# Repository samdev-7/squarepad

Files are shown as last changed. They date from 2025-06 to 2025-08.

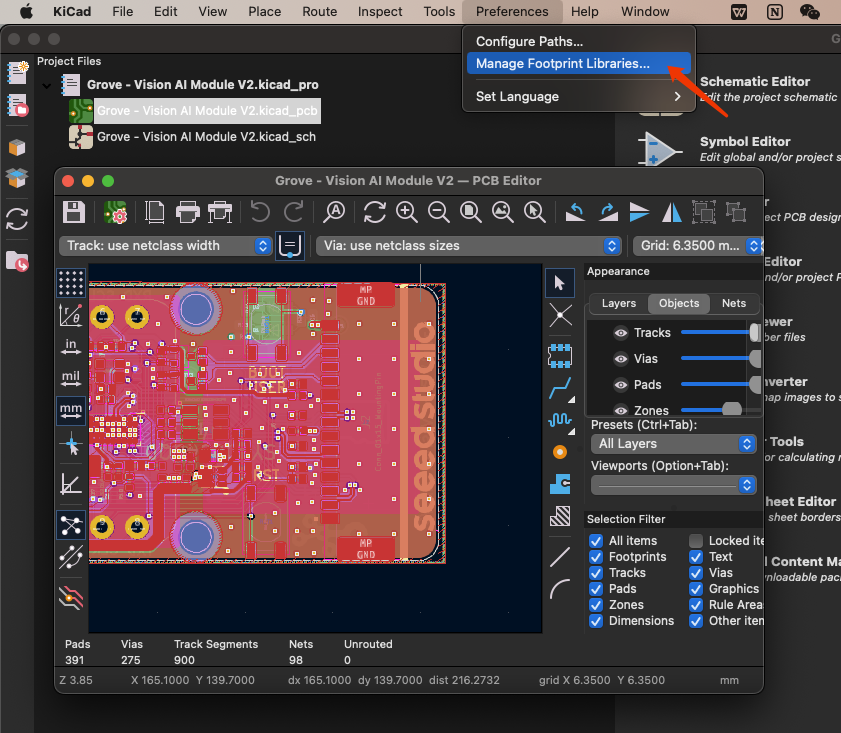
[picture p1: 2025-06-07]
pcb/OPL_Kicad_Library-master/images/4.png

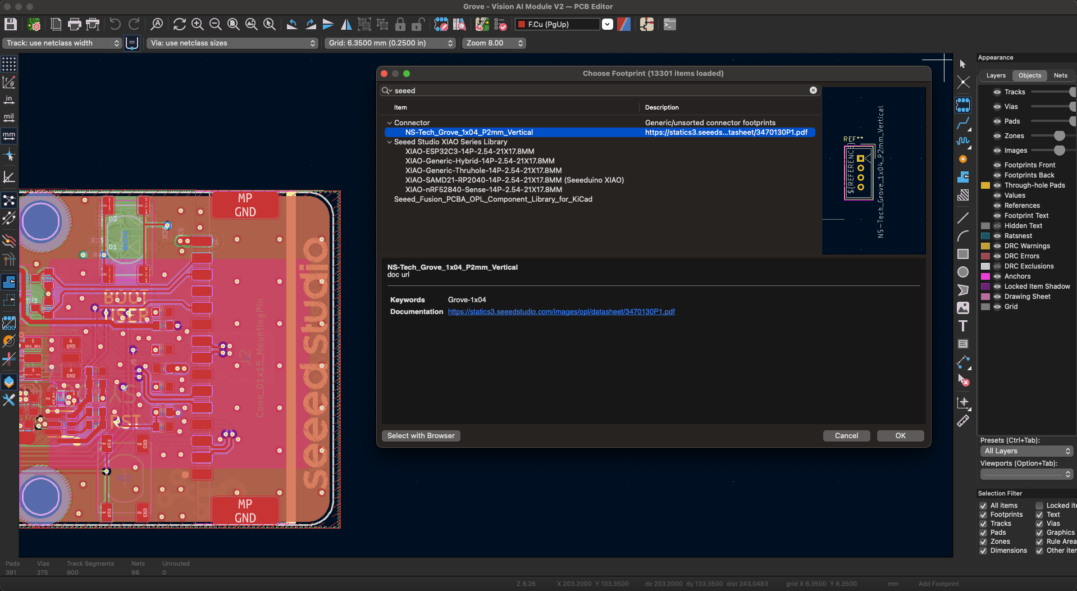
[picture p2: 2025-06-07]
pcb/OPL_Kicad_Library-master/images/19.png

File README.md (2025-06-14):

# Square Pad

A small but versatile macropad!

3D render of Square Pad
3D outline of Square Pad

Square pad is a KMK-powered, 8-key macropad with a rotary encoder, OLED display, and underglow lighting.  
It's inspired by the [Ocreeb MK2](https://github.com/sb-ocr/ocreeb-mk-2/tree/main) and was built for the [Hackpad](https://hackpad.hackclub.com/) program.

### Profile switching

The Square Pad can store and switch between several profiles, adapting the 8 keys and rotary encoder to whatever you need.  
To switch between presets, click the rotary encoder, rotate it to select a profile (shown on the OLED screen), and click to confirm. The underglow lighting will change colors, letting you know the current profile at a glance.

# Design

This is my first time designing a macropad/keyboard! Tons of Googling and bugging others here and there, but I (hopefully) did it!

## PCB

A total of 0 vias are on the PCB, ignoring THT and mounting holes. (there's no benefit to this, don't ask why)

Schematic of the Square Pad PCB

Layout of the Square Pad PCB

The PCB was designed in KiCad

## Case

The entire case can be 3D printed in 3 parts and assembled only with 6 M2x16mm screws and a tiny bit of hot glue for the screen. Each part is optimized for printability and quality with almost no supports.

3D exploded view of Square Pad

The case was designed in Onshape

## Firmware

Square Pad is powered by custom firmware written with [KMK](https://github.com/KMKfw/kmk_firmware). The custom firmware enabled easy profile switching and configuration.

# BOM

Everything you need to make your own Square Pad, minus the solder, glue, sweat, and tears.

## Electronics

- 1x XIAO RP2040 (with headers)
- 1x EC11E Rotary Encoder (with switch)
- 1x Rotary Encoder Knob
- 1x 0.91" OLED Display
- 8x Cherry MX Switches
- 8x Blank DSA Keycaps
- 9x Diode (THT)
- 12x SK6812 Mini LEDs
- Wires (for display)

## Case

- 6x M2x16mm Screw
- 1x case_top.stl
- 1x case_mid.stl
- 1x case_btm.stl
- 4x 10mm Rubber Feet (or just use hot glue)

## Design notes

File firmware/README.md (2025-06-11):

# Firmware

This folder contains the Firmware for Squre Pad, powered by KMK.

To install, download CircuitPython 9.x, install KMK, and the libraries: `neopixel`, `adafruit_display_text`, and `adafruit_displayio_ssd1306`, and copy all the Python files in this directory over.

Setup your profiles in `profile.py`.

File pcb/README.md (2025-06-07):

# PCB

This folder contains the PCB for the Squre Pad, designed in KiCad 8.0

To manufacture your own Square Pad PCB, the gerbers for JLCPCB are in `/production`.

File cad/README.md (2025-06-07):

# CAD

This folder contains the CAD for the Squre Pad.
The original CAD is available on Onshape: https://cad.onshape.com/documents/7a4a3820c147ef8980f0307c/w/4826e08d39faab4cb08c24dd/e/5c91f6f37143b2659c962470

## Case

To make the case, print one of each file in `/production/case`, models are already in the recommended orientation.  
The models have been optimized to require minimal supports. Supports are only needed for horizontals overhangings in the top part, and depending on your printer's bridging abilities, the USB Type-C port in the middle part may need supports.

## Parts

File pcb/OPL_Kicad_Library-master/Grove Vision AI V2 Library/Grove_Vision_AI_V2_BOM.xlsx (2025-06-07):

Layer Jump | Number | Name | Specification | Operating Temperature | MPN Code | Quantity | Base | Plug Position | Process
N | 301010000 | SMD RES 0R-5%-1/16W;0402 |  | -55°C to 155°C | RC0402JR-070RL | 3 | 1 | R29,R30,R39 | SMT1
N | 301010004 | SMD RES 10K-5%-1/16W;0402 |  | -55°C to 155°C | RC0402JR-0710KL | 7 | 1 | R5,R7,R8,R23,R24,R31,R38 | SMT1
N | 301010008 | SMD RES 510K-5%-1/16W;0402 |  | -55°C to 155°C | RC0402JR-07510KL | 1 | 1 | R35 | SMT1
N | 301010456 | SMD RES 100K-1%-1/16W;0402 |  | -55°C to 155°C | RC0402FR-07100KL | 7 | 1 | R6,R10,R11,R16,R32,R33,R37 | SMT1
N | 301010495 | SMD RES;5.1K-1%-1/16W;0402 |  | -55°C to 155°C | RC0402FR-075K1L | 3 | 1 | R2,R3,R36 | SMT1
N | 301010746 | SMD RES 2.2K-1%-1/16W;0402 |  | -55°C to 155°C | RC0402FR-072K2L | 10 | 1 | R1,R4,R13,R14,R15,R19,R20,R21,R22,R40 | SMT1
N | 301011331 | SMD RES 22.1K-1%-1/16W;0402 |  | -55°C to 155°C | RC0402FR-0722K1L | 2 | 1 | R26,R34 | SMT1
N | 302010004 | SMD CAP Ceramic 100nF-16V-10%-X7R;0402 |  | -55°C to 125°C | CC0402KRX7R7BB104 | 18 | 1 | C5,C8,C13,C20,C21,C22,C23,C24,C25,C26,C27,C29,C30,C31,C32,C35,C36,C39 | SMT1
N | 302010006 | SMD CAP Ceramic 10nF-50V-10%-X7R;0402 |  | -55°C to 125°C | CC0402KRX7R9BB103 | 1 | 1 | C3 | SMT1
N | 302010049 | SMD CAP Ceramic 12pF-50V-5%-NPO;0402 |  | -55°C to 125°C | CC0402JRNPO9BN120 | 2 | 1 | C14,C15 | SMT1
N | 302010051 | SMD CAP Ceramic 220nF-16V-10%-X7R;0402 |  | -55°C to 125°C | CC0402KRX7R7BB224 | 1 | 1 | C16 | SMT1
N | 302010407 | SMD CAP Ceramic 4.7uF-10V-10%-X5R;0402 |  | -55°C to 85°C | CC0402KRX5R6BB475 | 7 | 1 | C4,C6,C7,C9,C10,C28,C34 | SMT1
N | 302010519 | SMD CAP Ceramic 10uF-10V-20%-X5R;0402 |  | -55°C to 85°C | CC0402MRX5R6BB106 | 2 | 1 | C11,C37 | SMT1
N | 302013249 | SMD CAP Ceramic 1uF-10V-10%-X5R;0402 |  | -55°C to 85°C | CL05A105KP5NNNC | 5 | 1 | C1,C2,C17,C18,C19 | SMT1
N | 303010544 | SMD Inductor 4.7uH-20%-1.1A;0806 |  | -40°C to 105°C | VLS201610HBX-4R7M-1 | 1 | 1 | L1 | SMT1
N | 303011858 | SMD Inductor 470nH-20%-2.6A;0603 |  | -40°C to 125°C | TFM160808ALC-R47MTAA | 2 | 1 | L2,L3 | SMT1
N | 304011053 | SMD Diode Schottky 40V-1A;SOD-323 |  |  | B5819WS SL | 4 | 1 | D1,D2,D3,D4 | SMT1
N | 304090121 | SMD LED Clear-Green;0402 | As posted |  | BL-HGE37A-AV-TRB | 1 | 1 | LED2 | SMT1
N | 304090746 | SMD LED Clear-Yellow;0402 | As posted |  | 16-213/Y2C-AN2Q1B/3T | 1 | 1 | LED1 | SMT1
N | 305030071 | SMD MOSFET N-CH 20V-500mA;SOT-523 |  |  | CJ1012 | 5 | 1 | Q1,Q2,Q3,Q4,Q5 | SMT1
N | 306011444 | SMD Crystal;24MHz-12pF-10ppm-4P-2.0*1.6*0.5mm |  | -40°C to 85°C | Y2400FE001 | 1 | 1 | X1 | SMT1
N | 310011697 | SMD IC MCU;Dual Cortex-M55 Core(Max 400MHz)-With a 400MHz NPU;WLCSP-65 | L5.58*W2.27mm | -40°C to 85°C | HX6538-A01TWA | 1 | 1 | U1 | SMT1
N | 310032794 | SMD IC PMIC;DCDC Buck-ADJ-2.2MHz-4A;DFN1.5×1.5-6 |  | -40°C to 85°C | SY80004DQD | 2 | 1 | U4,U6 | SMT1
N | 310032813 | SMD IC PMIC;LDO-1.8V-300mA;XTDFN-1*1-4L |  | -40°C to 125°C | SGM2036S-1.8XXDH4G/TR | 1 | 1 | U3 | SMT1
N | 310071431 | SMD IC Interface USB to High Speed TTL;QFN16 | USB to High-Speed Serial Port | -40°C to 85°C | CH343P | 1 | 1 | U2 | SMT1
N | 310091468 | SMD IC Memory;128Mbit-1.8V;SOIC-8 |  | -40°C to 85°C | W25Q128JWSIQ | 1 | 1 | U5 | SMT1
N | 311020009 | SMD Top Button 4N;4P-L4.6*W3.2*H2.5mm |  | -20°C to 70°C | SKRPADE010 | 1 | 1 | RST1 | SMT1
N | 311020518 | SMD Top Button 1.57N;4P-L4.6*W3.2*H2.5mm |  | -30°C to 85°C | SKRPABE010 | 1 | 1 | BOOT1 | SMT1
N | 312030502 | SMD DIGITAL MIC OMNI -26dBFS;OCLGA-4:3.5*2.65*0.94mm |  | -40˚C to 100˚C | MSM261D3526H1CPM | 1 | 1 | MIC1 | SMT1
N | 319015667 | PCB;Grove - Vision AI Module V2 -蓝油白字-4层 | 20*40*1.6mm-ENIG-FR4;Steel mesh code；404012305 |  |  | 1 | 1 |  | SMT1
N | 320011358 | SMD USB TYPE C-W/P;12+4P-8.94*7.35*3.26mm |  | -30°C to 85°C | USB-31C-F-16P-L7.35 | 1 | 1 | J1 | SMT1
N | 320031231 | DIP Black Female Header VERT;1*7P-2.54-5.0mm |  | -40℃ to 105℃ |  | 2 | 1 | P8,P9 | Unit
N | 320060904 | SMD FPC CONN Bottom Contact;15P-1.0mm;L19.9*W6.76*H2.0mm |  | -30°C to 85°C | ST-FPC-W102015-D | 1 | 1 | J2 | SMT1
N | 320090535 | SMD uSD Card Holder;9+4P-L11.25*W6.96*H1.42mm |  | -25°C to 70°C | ST-TF-MR267 | 1 | 1 | J5 | SMT1
N | 320110032 | SMD Grove Female Header-Beige;4P-2.0-90D | 2.0-4PHorizontal Mount with Locking Socket |  | PHS-4A horizontal mount | 1 | 1 | J3 | SMT1

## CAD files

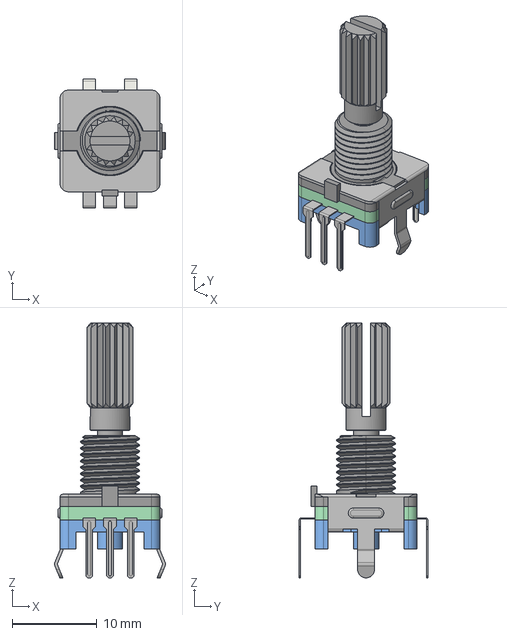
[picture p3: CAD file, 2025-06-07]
pcb/3d/EC11_Rotary_Encoder_Switched.step
13.1 x 15.3 x 30.1 mm

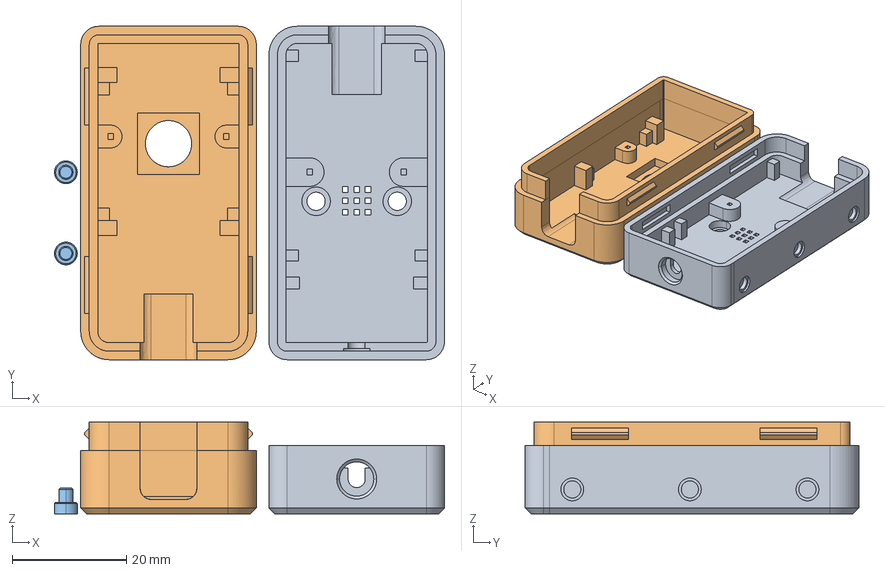
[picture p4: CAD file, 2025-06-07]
pcb/OPL_Kicad_Library-master/Grove Vision AI V2 Library/himax.stp
68.4 x 58.5 x 16.1 mm

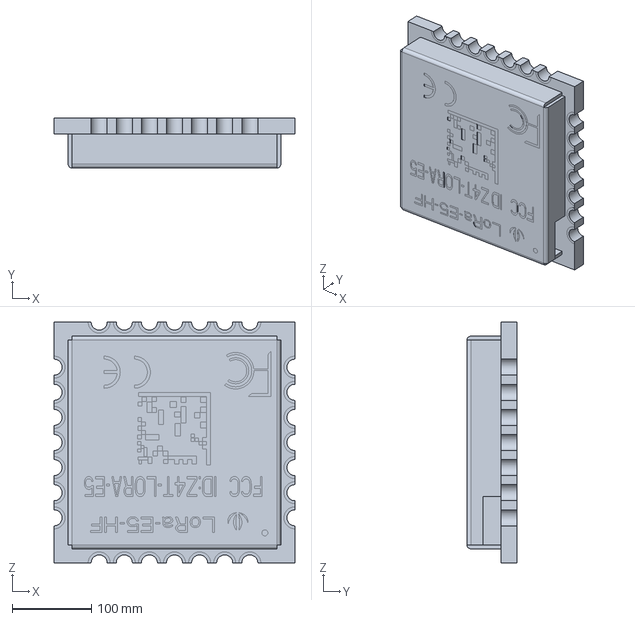
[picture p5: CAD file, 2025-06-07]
pcb/OPL_Kicad_Library-master/Seeed Studio Wio Series/Wio-E5-LE/LoRa-E5-LE-HF_3D_File.stp
304.8 x 63.8 x 304.8 mm

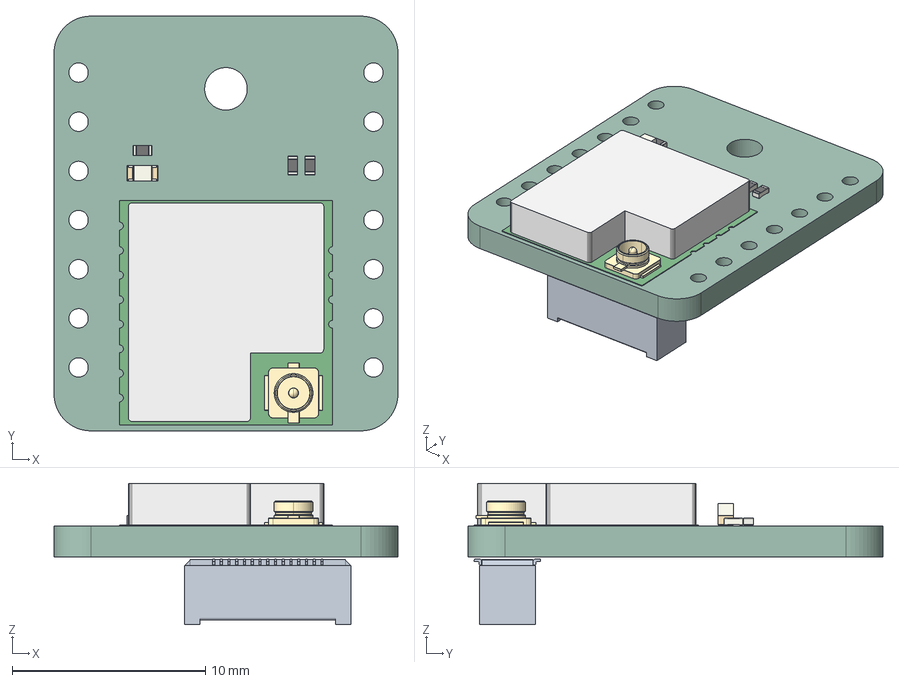
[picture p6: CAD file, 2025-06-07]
pcb/OPL_Kicad_Library-master/Seeed Studio Wio Series/Wio-SX1262/Wio-SX1262_for_XIAO_3D_file.step
17.8 x 21.4 x 7.30 mm
R_0402_1005Metric x 3
LED_0603_1608Metric
PCB
BF04-30pin-35H
Wio-SX1262 for XIAO V1.0_PCB

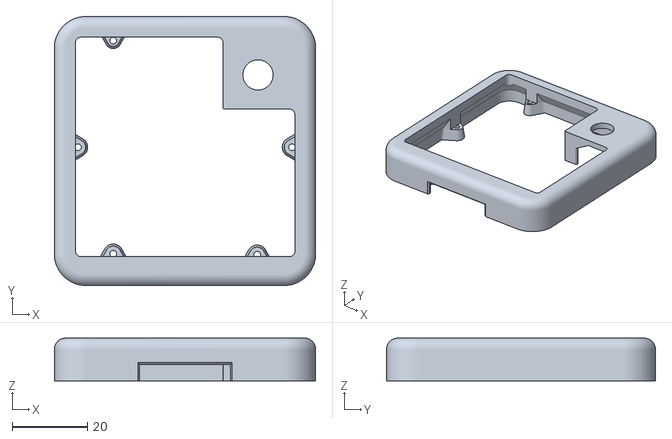
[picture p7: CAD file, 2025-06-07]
production/case/case_top.stl
69.3 x 71.3 x 11.4

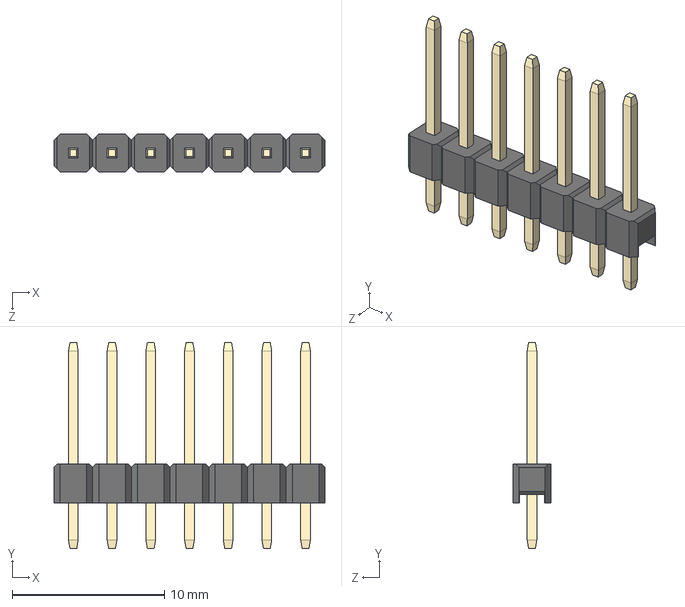
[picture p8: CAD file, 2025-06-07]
pcb/3d/1x7 Male Pin Header.step
17.8 x 13.5 x 2.50 mm

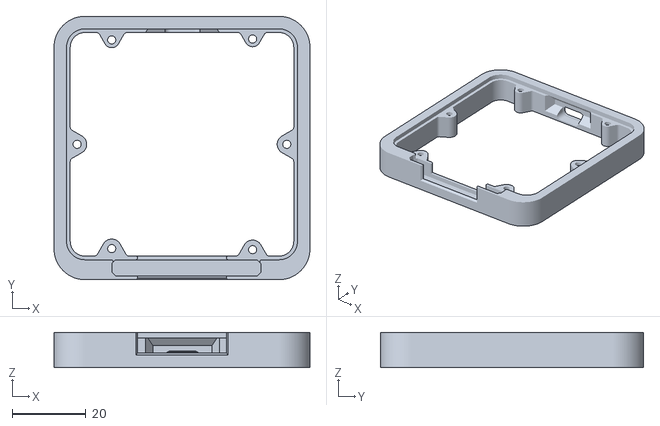
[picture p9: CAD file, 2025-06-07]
production/case/case_mid.stl
69.3 x 71.3 x 9.60

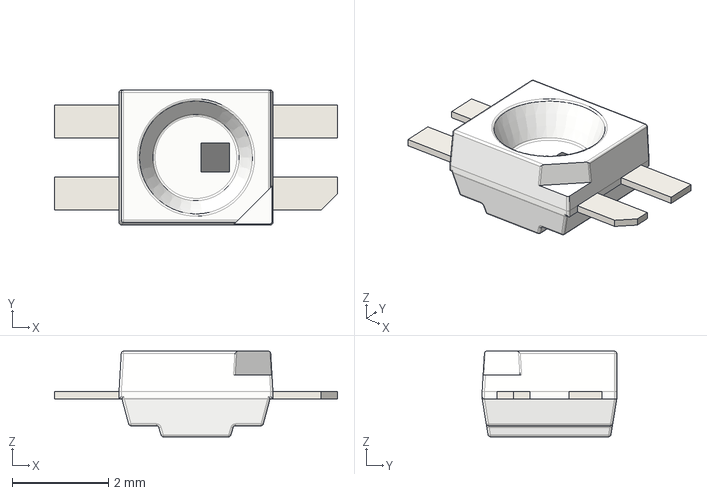
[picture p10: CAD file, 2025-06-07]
pcb/3d/LED_SK6812MINI-E.step
5.88 x 2.80 x 1.78 mm

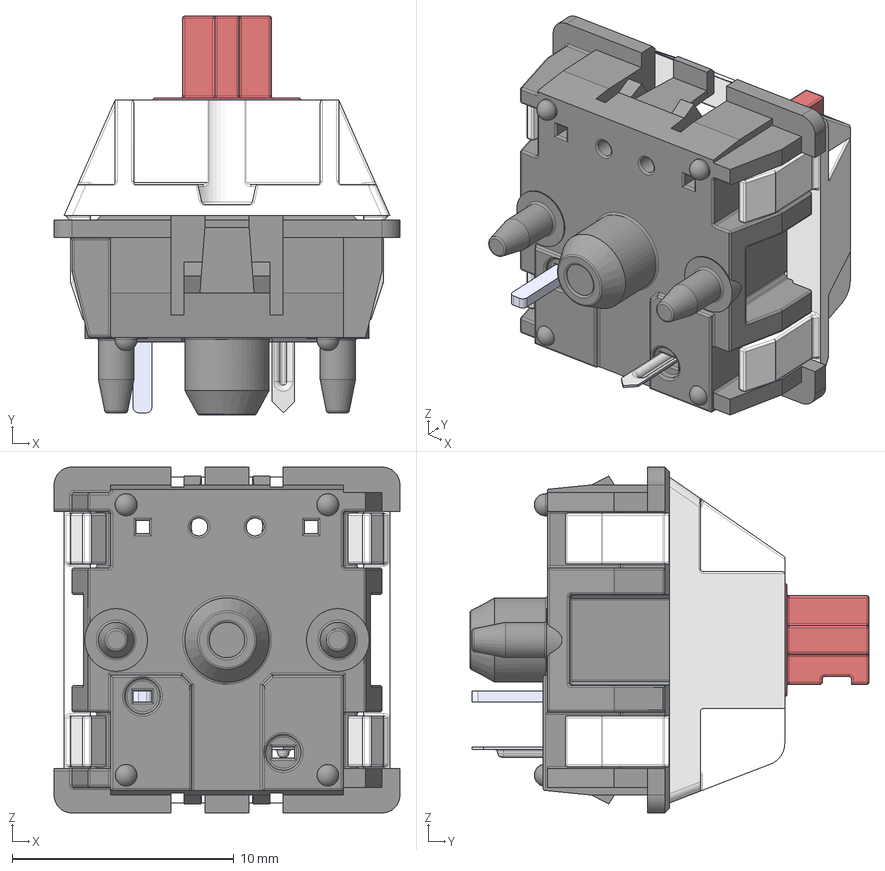
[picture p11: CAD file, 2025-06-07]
pcb/3d/Cherry MX-No LED.step
15.6 x 18.0 x 15.6 mm
Bottom
Pulsador
Top
Pieza5^Cherry MX
Pin1
Pin2

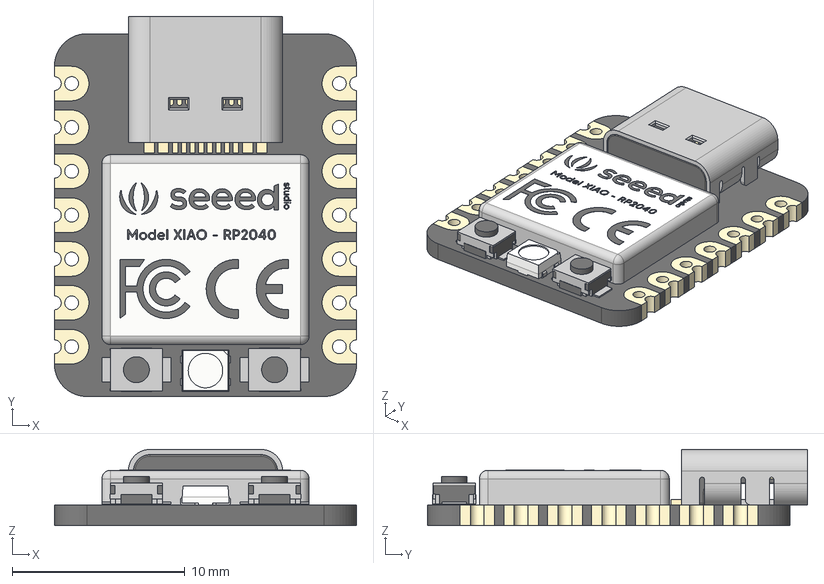
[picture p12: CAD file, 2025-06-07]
pcb/3d/Seeed Studio XIAO RP2040 v26.step
17.5 x 22.0 x 4.40 mm
type-c v2
smd_button v3
DOUT
DIN
VSS
VDD
smd_button v3(Mirror)

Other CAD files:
pcb/OPL_Kicad_Library-master/Grove Vision AI V2 Library/himax.3mf

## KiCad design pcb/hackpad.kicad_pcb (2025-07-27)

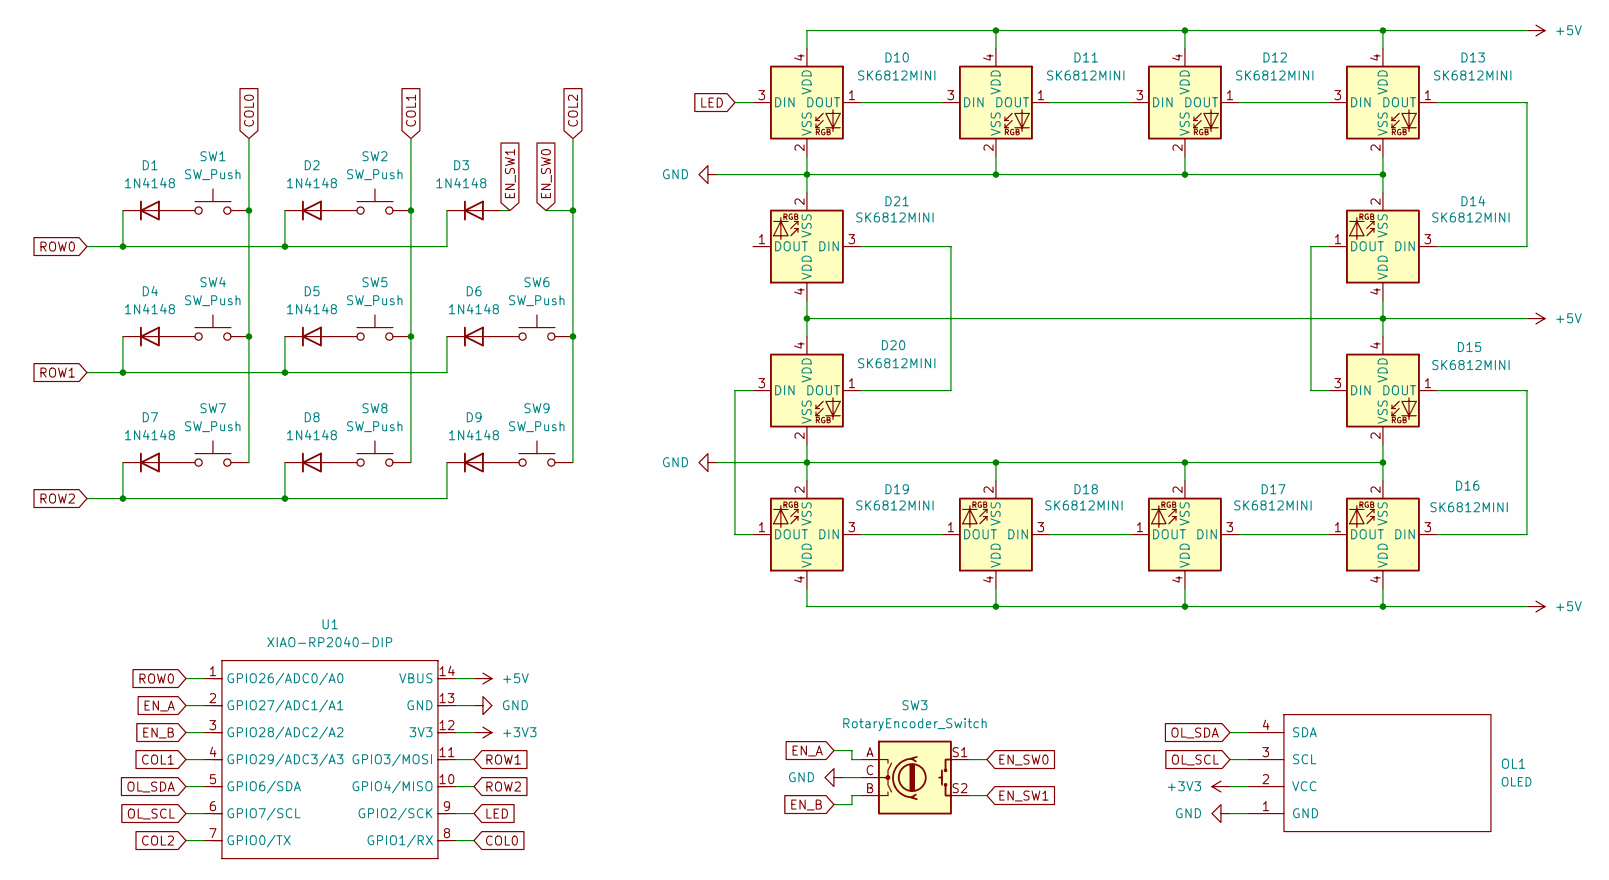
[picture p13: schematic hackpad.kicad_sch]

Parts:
D1, D2, D3, D4, D5, D6, D7, D8, D9: 1N4148; D_DO-35_SOD27_P7.62mm_Horizontal
D10, D11, D12, D13, D14, D15, D16, D17, D18, D19, D20, D21: SK6812MINI; LED_SK6812MINI_PLCC4_3.5x3.5mm_P1.75mm
OL1: OLED; SSD1306-0.91-OLED-4pin-128x32
SW1, SW2, SW4, SW5, SW6, SW7, SW8, SW9: SW_Push; SW_Cherry_MX_1.00u_PCB
SW3: RotaryEncoder_Switch; RotaryEncoder_Alps_EC11E-Switch_Vertical_H20mm
U1: XIAO-RP2040-DIP

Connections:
+3V3: OL1.2 (VCC), U1.12 (3V3)
+5V: D10.4 (VDD), D11.4 (VDD), D12.4 (VDD), D13.4 (VDD), D14.4 (VDD), D15.4 (VDD), D16.4 (VDD), D17.4 (VDD), D18.4 (VDD), D19.4 (VDD), D20.4 (VDD), D21.4 (VDD), U1.14 (VBUS)
COL0: SW1.2, SW4.2, SW7.2, U1.8 (GPIO1/RX)
COL1: SW2.2, SW5.2, SW8.2, U1.4 (GPIO29/ADC3/A3)
COL2: SW3.S1, SW6.2, SW9.2, U1.7 (GPIO0/TX)
EN_A: SW3.A, U1.2 (GPIO27/ADC1/A1)
EN_B: SW3.B, U1.3 (GPIO28/ADC2/A2)
EN_SW1: D3.2 (A), SW3.S2
GND: D10.2 (VSS), D11.2 (VSS), D12.2 (VSS), D13.2 (VSS), D14.2 (VSS), D15.2 (VSS), D16.2 (VSS), D17.2 (VSS), D18.2 (VSS), D19.2 (VSS), D20.2 (VSS), D21.2 (VSS), OL1.1 (GND), SW3.C, U1.13 (GND)
LED: D10.3 (DIN), U1.9 (GPIO2/SCK)
unnamed: D1.2 (A), SW1.1
unnamed: D2.2 (A), SW2.1
unnamed: D4.2 (A), SW4.1
unnamed: D5.2 (A), SW5.1
unnamed: D6.2 (A), SW6.1
unnamed: D7.2 (A), SW7.1
unnamed: D8.2 (A), SW8.1
unnamed: D9.2 (A), SW9.1
unnamed: D10.1 (DOUT), D11.3 (DIN)
unnamed: D11.1 (DOUT), D12.3 (DIN)
unnamed: D12.1 (DOUT), D13.3 (DIN)
unnamed: D13.1 (DOUT), D14.3 (DIN)
unnamed: D14.1 (DOUT), D15.3 (DIN)
unnamed: D15.1 (DOUT), D16.3 (DIN)
unnamed: D16.1 (DOUT), D17.3 (DIN)
unnamed: D17.1 (DOUT), D18.3 (DIN)
unnamed: D18.1 (DOUT), D19.3 (DIN)
unnamed: D19.1 (DOUT), D20.3 (DIN)
unnamed: D20.1 (DOUT), D21.3 (DIN)
OL_SCL: OL1.3 (SCL), U1.6 (GPIO7/SCL)
OL_SDA: OL1.4 (SDA), U1.5 (GPIO6/SDA)
ROW0: D1.1 (K), D2.1 (K), D3.1 (K), U1.1 (GPIO26/ADC0/A0)
ROW1: D4.1 (K), D5.1 (K), D6.1 (K), U1.11 (GPIO3/MOSI)
ROW2: D7.1 (K), D8.1 (K), D9.1 (K), U1.10 (GPIO4/MISO)

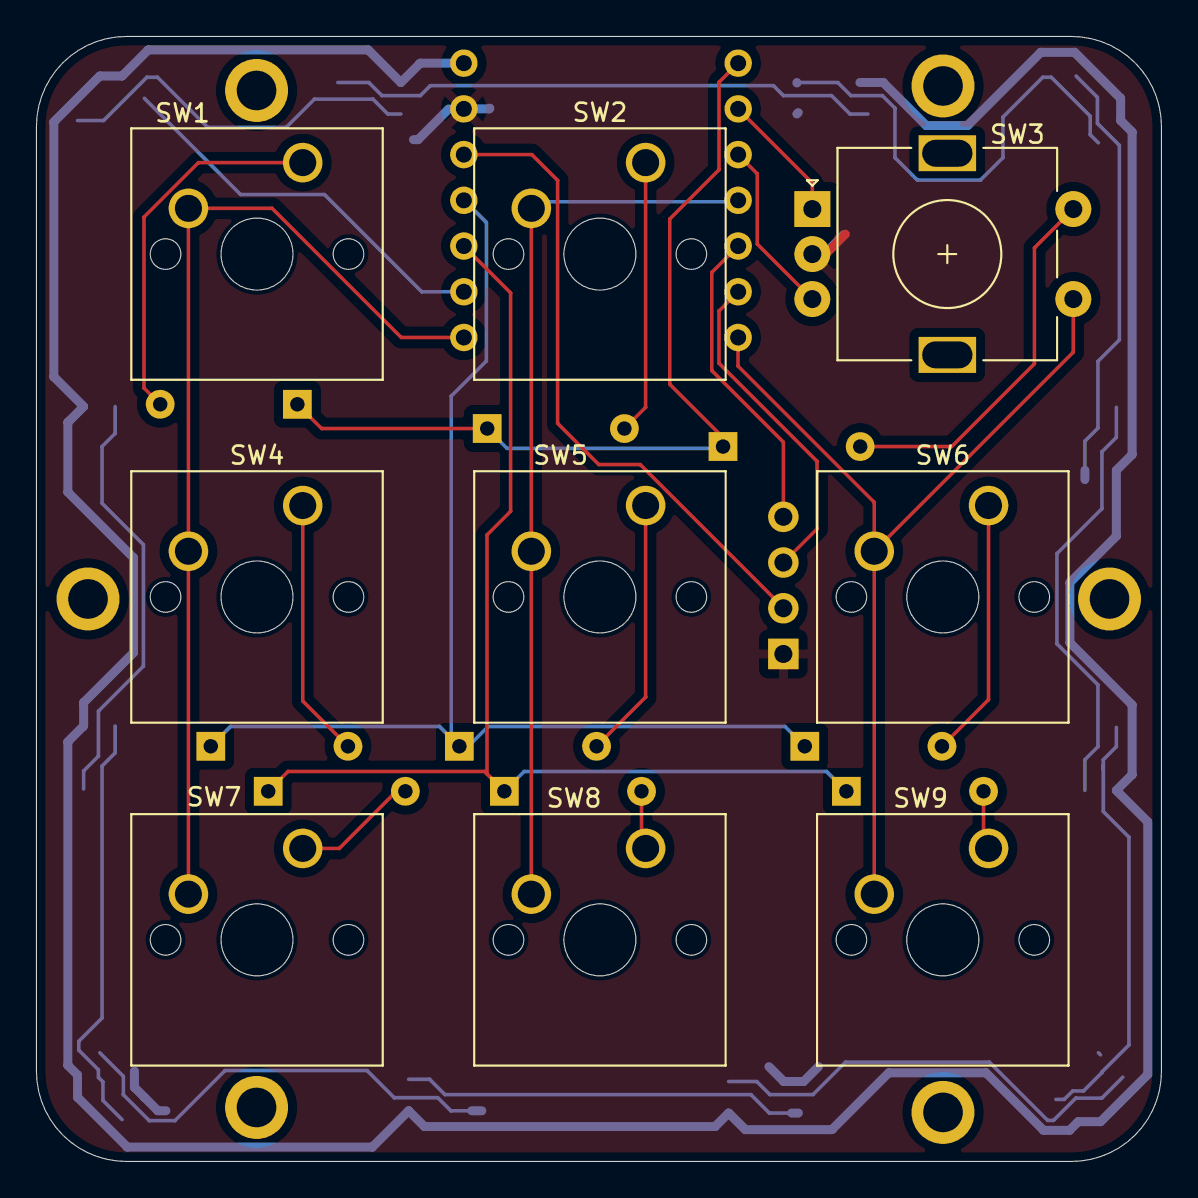
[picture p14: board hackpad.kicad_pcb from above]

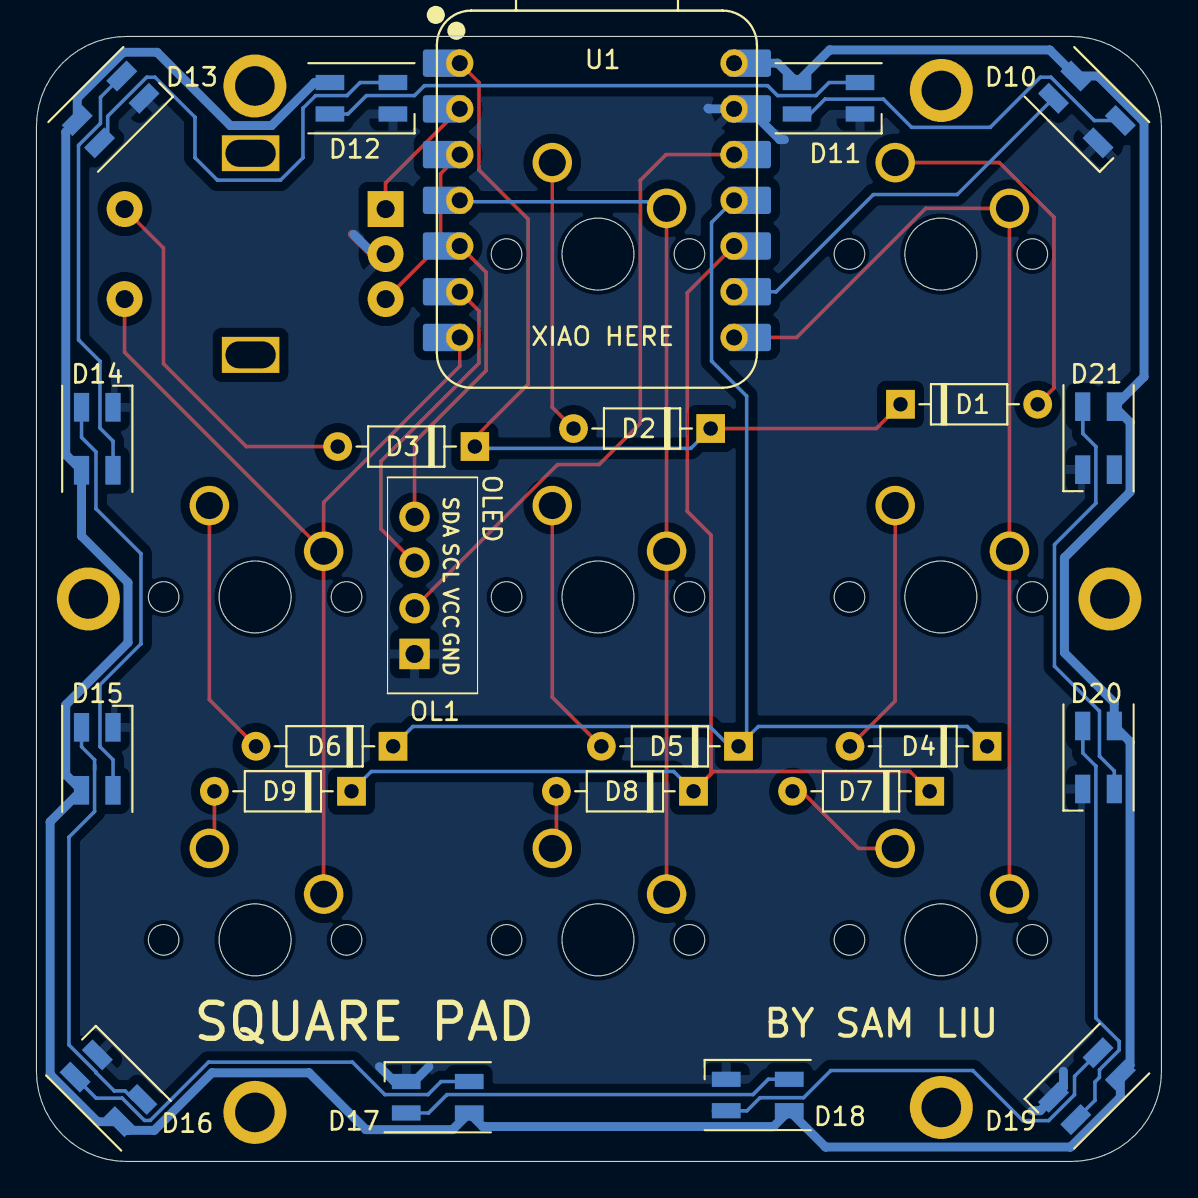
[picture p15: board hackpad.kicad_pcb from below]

Board: 2 copper layers, 62.5 x 62.5 mm, 32 parts (23 on the bottom side), 34 nets.

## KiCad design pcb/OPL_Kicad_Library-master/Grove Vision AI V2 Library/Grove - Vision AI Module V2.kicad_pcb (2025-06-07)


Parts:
BOOT1: SW_Push; SW_Push_1P1T_NO_Vertical_Wuerth_434133025816
C1, C2, C17, C18, C19: 1uF; C0402
C3: 10nF; C0402
C4, C6, C7, C9, C10, C28, C34: 4.7uF; C0402
C5, C8, C13, C20, C21, C22, C23, C24, C25, C26, C27, C29, C30, C31, C32, C35, C36, C39: 100nF; C0402
C11, C37: 10uF; C0402
C14, C15: 12pF; C0402
C16: 220nF; C0402
D1, D2, D3, D4: B5819WS; D0805_SOD323
D5, D6, D7, D8: DNP; R0402; MPN DF2S6.8FS
J1: USB_C_Receptacle_USB2.0; USB2.0-TYPE-C
J2: Conn_01x15_MountingPin; FPC_DNC_15P_1.0mm
J3: Conn_01x04_MountingPin; 4P-SMD-2.0mm-RIGHT
J5: ST-TF-MR267; SD-TF-MR267; MPN SD-TF-MR267
L1: VLS201610HBX-4R7M-1; L0806
L2, L3: 470nH; L0603
LED1: Yellow; LED0402
LED2: Green; LED0402
M1: XIAO Connector/DNP; XIAO_Socket
MIC1: MSM261D3526H1CPM; MIC6P-3.5X2.65X0.94MM
Q1, Q2, Q3, Q4, Q5: CJ1012; SOT523
R1, R4, R13, R14, R15, R19, R20, R21, R22, R40: 2.2k; R0402
R2, R3, R36: 5.1k; R0402
R5, R7, R23, R24: 10k; R0402
R6, R16, R32, R33: 100K; R0402; Power Rating 1%; MPN RC0402JR-074K7L
R8, R31, R38: 10K; R0402; Power Rating 5%; MPN RC0402JR-074K7L
R9, R12, R17, R18, R25, R27, R28: DNP; R0402
R10, R11, R37: 100k; R0402
R26, R34: 22K; R0402; Power Rating 1%; MPN RC0402JR-074K7L
R29, R30, R39: 0R; R0402
R35: 510k; R0402
RST1: SW_Push; SW_Push_1P1T_NO_Vertical_Wuerth_434133025816
TP1, TP2, TP3: Test Point; TP-D35MIL; Part Type Test Point
U1: HX6538; WLCSP65_5.6x2.3x0.56mm
U2: CH343P; QFN-16-EP_3x3mm_P0.5mm_EP1x1mm
U3: WR0331-18FF4R; X2SON-4
U4, U6: SY80004DQD; DFN6-0.5-1.5X1.5X0.65MM; MPN SY80004DQD
U5: W25Q128JWSIQ; SOIC-8_5.23x5.23mm_P1.27mm
X1: 24MHz; 4P2016

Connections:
1V8: C13.1, C19.2, C20.1, C21.1, C28.1, C29.2, Q1.1 (G), Q2.1 (G), R5.1, R21.2, R22.2, R25.1, TP2.1 (T), U1.F3 (VDDIO_SIF1), U1.G3 (VDDA_RX), U1.H5 (VDDA_TX), U1.L2 (VDDIO_SIF2), U3.1 (OUT), U5.8 (VCC)
/0V9: C4.1, C7.1, L1.2, U1.L4 (DCDC_OUT)
BOOTOPT0: D3.1 (K), R11.1, U1.F4 (BOOT_OPT)
GND: C1.2, C2.2, C3.2, C4.2, C5.2, C6.2, C7.2, C8.1, C9.2, C10.2, C11.1, C13.2, C14.2, C15.1, C17.2, C18.2, C19.1, C20.2, C21.2, C22.2, C23.2, C24.1, C25.1, C26.2, C27.1, C28.2, C29.1, C30.1, C31.2, C34.2, C35.1, C37.1, C39.1, D5.1, D6.1, D7.1, D8.1, J1.A1_B1_A12_B12 (GND), J1.S1 (SHIELD), J2.1, J2.4, J2.7, J2.10, J2.MP (MountPin), J3.4, J3.MP (MountPin), J5.S1 (SHD1), J5.S2 (SHD2), J5.S3 (SHD3), J5.S4 (SHD4), J5.T6 (VSS), LED2.1 (K), M1.13 (GND), MIC1.4 (GND), MIC1.5 (L/R), MIC1.6 (GND), Q3.2 (S), R2.2, R3.2, R10.2, R11.2, R23.2, R26.1, R34.1, R37.2, RST1.2, TP3.1 (T), U1.C5 (GND1), U1.G4 (GND2), U1.H3 (GND3), U1.L3 (GND4), U1.M2 (GND5), U1.M4 (GND6), U2.2 (GND), U2.17 (EPAD), U3.2 (GND), U3.T (GND), U4.4 (GND), U5.4 (GND), U6.4 (GND), X1.2 (1), X1.4 (3)
GROVE_5V_IN: C18.1, C34.1, C35.2, J3.3, R14.1, R15.1, R31.2, R32.2, U6.6 (IN)
I2CS0_SCL/5V: J3.1, Q4.3 (D), R14.2
I2CS0_SDA/5V: J3.2, Q5.3 (D), R15.2
M_3V3_SCL: J2.13, Q1.3 (D), R19.2
M_3V3_SDA: J2.14, Q2.3 (D), R20.2
unnamed: BOOT1.2, R4.2
unnamed: D1.2 (A), R36.2
unnamed: C9.1, C10.1, C27.2, D2.1 (K), D4.1 (K), R6.2, R8.2, U4.6 (IN)
unnamed: BOOT1.1, D3.2 (A), R36.1
unnamed: J1.A5 (CC1), R2.1
unnamed: J1.B5 (CC2), R3.1
unnamed: LED1.2 (A), R38.1
unnamed: LED1.1 (K), Q3.3 (D)
unnamed: LED2.2 (A), R24.2
unnamed: M1.12 (3V3), R39.2
unnamed: MIC1.2 (CLK), R29.1
unnamed: MIC1.3 (DATA), R30.1
unnamed: Q3.1 (G), R37.1, R40.2
unnamed: R10.1, U1.E4 (TEST_MODE)
unnamed: L1.1, U1.L5 (VX1)
unnamed: C14.1, R35.1, U1.G2 (XTAL_24M_I), X1.3 (4)
unnamed: C15.2, R35.2, U1.F1 (XTAL_24M_O), X1.1 (2)
unnamed: C16.2, U2.13 (RTS)
unnamed: R8.1, U4.1 (EN)
unnamed: C32.1, R16.1, R26.2, U4.3 (FB)
unnamed: L2.1, U4.5 (LX)
unnamed: R6.1, U4.2 (PG)
unnamed: R31.1, U6.1 (EN)
unnamed: C36.1, R33.1, R34.2, U6.3 (FB)
unnamed: L3.1, U6.5 (LX)
unnamed: R32.1, U6.2 (PG)
PA0/3V3: M1.1 (D0/A0), U1.D4 (PA0)
PA1/VMUTE/3V3: J2.11, U1.C4 (PA1)
PA2/I2CS0_SCL/3V3: M1.6 (D5/SCL), Q4.2 (S), R1.1, R17.2, U1.A4 (PA2)
PA3/I2CS0_SDA/3V3: M1.5 (D4/SDA), Q5.2 (S), R13.1, R18.2, U1.B4 (PA3)
PB0/RX0/3V3: U1.A5 (PB0), U2.4 (TXD)
PB1/TX0/3V3: U1.B5 (PB1), U2.5 (RXD)
PB2/SSPIM_DO/3V3: D7.2, J5.T3 (CMD), M1.11 (D10/MOSI), R12.2, U1.N5 (PB2)
PB3/SSPIM_DI/3V3: D5.2, J5.T7 (DAT0), M1.10 (D9/MISO), R9.2, U1.M3 (PB3)
PB4/SSPIM_SCLK/3V3: D6.2, J5.T5 (CLOCK), M1.9 (D8/SCK), R27.2, U1.N4 (PB4)
PB5/SSPIM_~CS/3V3: D8.2, J5.T2 (CD/DAT3), R28.2, U1.N3 (PB5)
PB6/UART1_RX/3V3: M1.7 (D6/TX), U1.N1 (PB6)
PB7/UART1_TX/3V3: M1.8 (D7/RX/SS), U1.M1 (PB7)
PB8/3V3: M1.3 (D2/A2), U1.L1 (PB8)
PB9/PDM_CLK/3V3: R29.2, U1.F5 (PB9)
PB10/PDM_DATA0/3V3: R30.2, U1.G5 (PB10)
PB11/3V3: M1.2 (D1/A1), U1.J3 (PB11)
QSPI_CLK: U1.C2 (QSPI_CLK), U5.6 (CLK)
QSPI_CS: R5.2, U1.B2 (QSPI_CS), U5.1 (~CS)
QSPI_D0: U1.B1 (QSPI_DIO0), U5.5 (DI(IO0))
QSPI_D1: U1.D3 (QSPI_DIO1), U5.2 (DO(IO1))
QSPI_D2: U1.A1 (QSPI_DIO2), U5.3 (IO2)
QSPI_D3: U1.E3 (QSPI_DIO3), U5.7 (IO3)
RST: C3.1, C16.1, M1.4 (D3/A3), R7.1, RST1.1, U1.E5 (RESETN)
RX_CK_N: J2.8, U1.E2 (RX_CKN)
RX_CK_P: J2.9, U1.F2 (RX_CKP)
RX_D0_N: J2.2, U1.D2 (RX_DN0)
RX_D0_P: J2.3, U1.C1 (RX_DP0)
RX_D1_N: J2.5, U1.D1 (RX_DN1)
RX_D1_P: J2.6, U1.E1 (RX_DP1)
SEN_D1/SD~INSERT: J5.G1 (SWITCH), R25.2, U1.G1 (SEN_D1)
SEN_I2CM_SCL: Q1.2 (S), R21.1, U1.A3 (SEN_I2CM_SCL)
SEN_I2CM_SDA: Q2.2 (S), R22.1, U1.B3 (SEN_I2CM_SDA)
UD+: J1.A6 (D+), J1.B6 (D+), U2.7 (D+)
UD-: J1.A7 (D-), J1.B7 (D-), U2.8 (D-)
USER_LED/1V8: R40.1, U1.K2 (SEN_D2)
USR_BTN/1V8: D1.1 (K), R23.1, U1.H1 (SEN_D0)
V33IO: C2.1, C31.1, U2.1 (VIO), U2.6 (V3)
VBUS: C1.1, C30.2, D4.2 (A), J1.A4_B4_A9_B9 (VBUS), U2.3 (VDD5), U2.9 (VBUS)
VCC_3V3: C5.1, C6.1, C8.2, C11.2, C17.1, C22.1, C23.1, C24.2, C25.2, C26.1, C32.2, C36.2, C37.2, C39.2, J2.15, J5.T4 (VDD), L2.2, L3.2, MIC1.1 (VDD), Q4.1 (G), Q5.1 (G), R1.2, R4.1, R7.2, R9.1, R12.1, R13.2, R16.2, R17.1, R18.1, R19.1, R20.1, R24.1, R27.1, R28.1, R33.2, R38.2, R39.1, TP1.1 (T), U1.D5 (VDDIO_AON), U1.M5 (VDDA_DCDC), U1.N2 (VDDIO_PIF), U3.3 (EN), U3.4 (IN)
VMAIN: D2.2 (A), M1.14 (VUSB)

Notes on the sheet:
MIPI CSI
AON 3V3
MIPI DSI
PIF 3V3
SIF only 1V8
Imax=600mA
23/11/14
Grove - Vision AI Module V2
JN.FUONG



Board: 4 copper layers, 40.0 x 20.0 mm, 112 parts (31 on the bottom side), 75 nets.

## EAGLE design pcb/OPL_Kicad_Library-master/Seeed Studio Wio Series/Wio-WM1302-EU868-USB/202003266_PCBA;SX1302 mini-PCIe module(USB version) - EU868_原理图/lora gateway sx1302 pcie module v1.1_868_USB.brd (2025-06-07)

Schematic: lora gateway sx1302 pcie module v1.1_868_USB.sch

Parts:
ANT1: U.FL-R-SMT-1(10); U-FL3P-SMD-2.6X2.6X1.0MM
ANT2: DNP; U-FL3P-SMD-2.6X2.6X1.0MM
C1, C12, C15, C19, C23, C25, C26, C29, C32, C41, C43, C45, C65, C67, C80, C83, C86, C88: 100nF; C0402
C2, C75: 2.2pF; C0402
C3, C92: 10uF; C0603
C4, C8, C11, C16, C17, C18, C64: 56pF; C0402
C5, C6, C9, C10: 3.6pF; C0402
C7, C91: 5.6pF; C0402
C13, C20, C21, C24, C28, C35, C39, C40, C42, C44, C47, C48, C76, C87, C89: 1uF; C0402
C14, C38, C57, C66, C81, C84: 10pF; C0402
C22, C27, C33: 10uF; C0603@1
C30, C56, C74, C77, C78, C79: DNP; C0402
C31: DNP; C0603@1
C34, C46, C63: 470nF; C0402
C36: 47nF; C0402
C37: 47pF; C0402
C49: 4.7uF; C0603
C50, C62, C85: 10nF; C0402
C51: 1nF; C0402
C52, C55: 100pF; C0402
C53, C60, C61: 3.3pF; C0402
C54: 39pF; C0402
C58: 1.3pF; C0402
C59, C68, C73: 1.8pF; C0402
C69, C70, C71, C72: 10uF; C0805
C82: 2.7pF; C0402
C90: 2.2uF; C0603
D1, D4: Green; LED-0402
D2: Red; LED-0402
D3: Blue; LED-0402
D5: LXES15AAA1-153; ESD-0402
D6: DNP; ESD-0402
D7: BAT54XV2T1G; SOD-523
FB1: BLM15PD121SN1D; F0402
J1: DNP; PCIE52P-0.8-50.95X30MM
L1: LQP15MN1N2B02D; L0402
L2: LQW15AN6N8G00D; L0402
L4: 0R; F0603
L5: LQH44PN1R0NP0L; L4.4X3.0MM
L6, L14, L20: MLZ2012M150WT; L0805
L7, L15, L18, L21: DNP; L0402
L8: LQW15AN3N0B00; L0402
L9: LQW15AN47NJ00D; L0402
L10: LQW15AN2N5B00D; L0402
L11: LQW15AN4N7C00D; L0402
L12, L13: LQW15AN12NG00D; L0402
L16: LQW15AN7N5G00D; L0402
L17, L24: LQW15AN5N6C10D; L0402
L22: LQW15AN15NG00D; L0402
Q8: CJ2101; SOT-323
Q10: CJ2102; SOT-323
R1, R4, R33, R34, R38, R42, R57, R65, R71: 10k; R0402
R2, R7: 0R; R0603
R3, R8, R11, R12, R43, R44, R46, R49, R51, R55, R56, R59, R60, R61, R62, R63, R67, R70, R72, R73, R74, R75, R76, R81: DNP; R0402
R5, R10, R14, R15, R16, R39, R40, R41: 100R; R0402
R6, R9, R37: 220R; R0402
R13, R35, R52: DNP; R0603
R17, R18, R19, R20, R21, R22, R23, R24, R25, R26, R27, R28, R29, R36, R45, R48, R50, R53, R54, R69, R77: 0R; R0402
R30, R31, R32: 680R; R0402
R47, R79: 1k; R0402
R58, R68: 4.7k; R0402
R64, R66: 22R; R0402
R78, R82: 100k; R0402
R80: 10R; R0402
R83, R87: 200k_1%; R0402
S1, S2, S3, S4, S5, S6: 323030226; SHIELD_CLIP
TP1, TP2, TP3, TP4, TP5, TP6, TP7, TP8, TP9, TP10, TP14: TEST-POINT-35; TP_3535
TP15: TEST-POINT'4545'; TP-D45MIL
U1: SX1302IMLTRT; QFN68-0.35-7X7X0.75MM
U2, U8, U10: HDF866A3-S6; FILTER6P-1.1-3X3X1.3MM
U3, U4: DNP; SOT-23-5
U5, U7: SX1250IMLTRT; QFN24G-0.5-4X4MM
U6: MP2161GJ; TSOT23-8
U9: SKY66420-11; MODULE16P-0.5-3X3X0.75MM
U11: SX1262IMLTRT; QFN24G-0.5-4X4MM
U12: STM32L412K8U6; UFQFPN32-0.5-5X5MM
U13: STTS751; UDFN-6L
X1: DSB221SDN; X4-SMD-2.5X2.0X1.0MM
X3: 32.768kHz; X2-SMD-3.2X1.5X0.55MM

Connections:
32MHZ: R6.2, R9.2, R37.2, X1.3 (OUT)
1302_CS: R33.2, R43.1, U1.1 (HOST_CSN), U12.10 (PA4)
1302_RESET: C1.2, D7.-, R1.2, U1.7 (RESET), U12.8 (PA2)
1302_RESET_HOST: D7.+, R59.1
CONFIG_OK: R31.1, U1.66 (GPIO0)
DM: J1.36, R66.1
DP: J1.38, R64.1
FEM_CS: R14.2, R34.1, U1.10 (RADIO_CTRL0), U3.3 (CE)
FEM_PA_ON: R15.2, U1.16 (RADIO_CTRL4)
GND: ANT1.GND1, ANT1.GND2, ANT2.GND1, ANT2.GND2, C2.1, C3.1, C5.1, C7.1, C9.1, C12.1, C13.1, C15.1, C16.1, C17.1, C18.1, C19.1, C20.1, C21.1, C22.1, C23.1, C24.1, C25.1, C26.1, C27.1, C28.1, C29.1, C30.1, C31.1, C32.1, C33.1, C34.1, C35.1, C36.1, C37.1, C39.1, C40.1, C41.1, C42.1, C43.1, C44.1, C45.1, C46.1, C47.1, C48.1, C49.1, C50.1, C51.1, C52.1, C55.1, C56.1, C57.1, C58.1, C60.2, C61.2, C62.1, C63.2, C65.2, C67.2, C69.1, C70.1, C71.1, C72.1, C73.2, C74.2, C76.1, C77.2, C78.2, C80.1, C81.2, C82.2, C83.1, C84.2, C85.1, C86.1, C87.1, C88.1, C89.1, C90.1, C92.1, D1.-, D2.-, D3.-, D4.-, D5.1, D6.1, J1.4 (GND), J1.9 (GND), J1.15 (GND), J1.18 (GND), J1.21 (GND), J1.26 (GND), J1.27 (GND), J1.29 (GND), J1.34 (GND), J1.35 (GND), J1.37 (GND), J1.40 (GND), J1.43 (GND), J1.50 (GND), J1.S1 (GND), J1.S2 (GND), Q10.2 (S), R1.1, R4.1, R11.1, R12.1, R17.2, R53.1, R53.2, R54.1, R54.2, R55.1, R55.2, R57.2, R73.1, R74.1, R74.2, R87.1, S1.S1, S1.S2, S1.S3, S1.S4, S1.S5, S2.S1, S2.S2, S2.S3, S2.S4, S2.S5, S3.S1, S3.S2, S3.S3, S3.S4, S3.S5, S4.S1, S4.S2, S4.S3, S4.S4, S4.S5, S5.S1, S5.S2, S5.S3, S5.S4, S5.S5, S6.S1, S6.S2, S6.S3, S6.S4, S6.S5, TP3.T, U1.6 (GND), U1.9 (GND), U1.15 (GND), U1.24 (GND), U1.25 (GND), U1.39 (GND), U1.46 (GND), U1.55 (GND), U1.62 (GND), U1.69 (GND), U2.1 (GND), U2.3 (GND), U2.4 (GND), U2.6 (GND), U3.2 (VSS), U4.2 (VSS), U5.7 (GND), U5.20 (GND), U5.PAD, U6.4 (PGND), U6.6 (AGND), U7.7 (GND), U7.20 (GND), U7.PAD, U8.1 (GND), U8.3 (GND), U8.4 (GND), U8.6 (GND), U9.10 (GND), U9.12 (GND), U9.17 (EPAD), U10.1 (GND), U10.3 (GND), U10.4 (GND), U10.6 (GND), U11.2 (GND), U11.5 (GND), U11.8 (GND), U11.20 (GND), U11.PAD, U12.16 (VSS), U12.32 (VSS), U12.PAD, U13.4 (ADDR/!THERM), U13.5 (GND), X1.2 (GND)
HOST_CS0: J1.51, R43.2
HOST_CS1: J1.25, R51.2
HOST_IO1: J1.33, R61.2
HOST_IO2: J1.31, R63.2
HOST_IO3: J1.23
HOST_IO4: J1.8, R67.2
HOST_IO5: J1.10, R60.2
HOST_IO6: J1.12
HOST_MISO: R39.1, R44.2
HOST_MOSI: J1.49, R46.2
HOST_RST: J1.22, R59.2, R77.2
HOST_SCK: J1.45, R49.2
I2C_SCL: R68.2, R76.1, R81.1, U12.29 (PB6), U13.1 (SCL)
I2C_SDA: R58.2, R70.1, R75.1, U12.30 (PB7), U13.6 (SDA)
MCU_RESET: C85.2, R71.2, R77.1, TP5.T, U12.4 (NRST)
MISO: R44.1, R45.1, U1.2 (HOST_MISO), U11.16 (MISO)
MISO_A: U1.42 (RADIO_A_MISO), U5.16 (MISO)
MISO_B: U1.33 (RADIO_B_MISO), U7.16 (MISO)
MOSI: R5.2, R40.2, R46.1, R48.1
MOSI_A: U1.67 (RADIO_A_MOSI), U5.17 (MOSI)
MOSI_B: U1.19 (RADIO_B_MOSI), U7.17 (MOSI)
unnamed: C11.2, U9.2 (RX)
unnamed: TP15.T, U6.1 (PG)
unnamed: C8.1, R11.2, R52.2, U8.5 (OUT)
unnamed: C2.2, L11.2, R52.1, U8.2 (IN)
unnamed: C11.1, R13.2, U2.2 (IN)
unnamed: C4.2, U9.1 (TX)
unnamed: C68.1, C74.1, C75.2
unnamed: C65.1, L18.2, R36.2, U11.1 (VDD_IN)
unnamed: C66.2, R37.1
unnamed: L5.1, U6.3 (SW)
unnamed: R83.1, R87.2, U6.7 (FB)
unnamed: R3.1, R4.2, X1.1 (ENABLE)
unnamed: C14.1, U5.3 (XTA)
unnamed: C62.2, L4.1, R3.2, X1.4 (VDD)
unnamed: R5.1, U1.3 (HOST_MOSI)
unnamed: D4.+, R47.2
unnamed: R10.1, U1.4 (HOST_SCK)
unnamed: R82.2, U6.8 (EN)
unnamed: R8.1, U4.3 (CE)
unnamed: C14.2, R6.1
unnamed: L6.2, U5.8 (DCC_SW)
unnamed: C34.2, L6.1, L7.2, U5.6 (VREG)
unnamed: C64.1, C82.1, L24.2
unnamed: R19.1, U1.34 (RADIO_B_CLK_I)
unnamed: C16.2, R14.1, U9.4 (CSD)
unnamed: C38.1, U7.3 (XTA)
unnamed: C36.2, C37.2, L9.2, U5.1 (VR_PA)
unnamed: C38.2, R9.1
unnamed: L14.2, U7.8 (DCC_SW)
unnamed: C46.2, L14.1, L15.2, U7.6 (VREG)
unnamed: C54.2, L11.1
unnamed: C7.2, C53.2, C54.1, L10.2
unnamed: C4.1, C8.2, R12.2
unnamed: C17.2, R15.1, U9.5 (CPS)
unnamed: C18.2, R16.1, U9.6 (CTX)
unnamed: R17.1, U1.20 (SP_VALID)
unnamed: R18.1, U1.32 (RADIO_B_IQ3)
unnamed: R20.1, U1.35 (RADIO_B_IQ0)
unnamed: R24.1, U1.41 (RADIO_A_IQ3)
unnamed: R21.1, U1.36 (RADIO_B_IQ1)
unnamed: R22.1, U1.37 (RADIO_B_IQ4)
unnamed: R23.1, U1.38 (RADIO_B_IQ2)
unnamed: R25.1, U1.43 (RADIO_A_CLK_I)
unnamed: R26.1, U1.44 (RADIO_A_IQ0)
unnamed: R27.1, U1.45 (RADIO_A_IQ1)
unnamed: R28.1, U1.48 (RADIO_A_IQ4)
unnamed: R29.1, U1.49 (RADIO_A_IQ2)
unnamed: D3.+, R32.2
unnamed: D2.+, R31.2
unnamed: D1.+, R30.2
unnamed: Q8.1 (G), Q10.3 (D), R78.2
unnamed: C1.1, R80.1
unnamed: L1.1, U9.16 (VCC1)
unnamed: L2.1, L8.1, U9.13 (PA_OUT)
unnamed: C56.2, C57.2, L8.2, L16.1
unnamed: C58.2, L16.2, U9.11 (TX_IN)
unnamed: C59.2, C60.1, L17.1, U9.9 (ANT)
unnamed: C61.1, C91.1, L17.2, L24.1
unnamed: C66.1, U11.3 (XTA)
unnamed: ANT1.D, C64.2, D5.2
unnamed: R35.2, R62.1, R69.2, U10.2 (IN)
unnamed: C63.1, L18.1, L20.1, U11.7 (VREG)
unnamed: R35.1, U9.7 (LNA_IN), U10.5 (OUT)
unnamed: L20.2, U11.9 (DCC_SW)
unnamed: J1.47, R39.2
unnamed: R40.1, U11.17 (MOSI)
unnamed: R41.1, U11.18 (SCK)
unnamed: C6.1, C10.1, C75.1, R13.1, U2.5 (OUT)
unnamed: R69.1, U9.8 (RX_FLT)
unnamed: C78.1, C79.1, L21.2
unnamed: ANT2.D, C79.2, D6.2
unnamed: C59.1, C91.2
unnamed: C77.1, L21.1, R62.2
unnamed: R65.2, U13.2 (!EVENT)
unnamed: C52.2, FB1.1, L1.2, U9.15 (VCC0)
unnamed: R64.2, U12.22 (PA12)
unnamed: R66.2, U12.21 (PA11)
unnamed: C92.2, Q10.1 (G), R79.2
unnamed: R56.2, R57.1, U12.31 (BOOT0)
unnamed: R72.2, R73.2, U12.6 (PA0-CLK_IN)
unnamed: C81.1, U12.2 (PC14-OSC32_IN), X3.2
unnamed: C84.1, U12.3 (PC15-OSC32_OUT), X3.1
unnamed: J1.14, R76.2
unnamed: J1.16, R70.2
unnamed: J1.30, R81.2
unnamed: J1.32, R75.2
PPS: J1.19, TP2.T, U1.8 (PPS), U12.27 (PB4)
RADIO_A_CLK_32M: R25.2, R72.1, U5.14 (BUSY)
RADIO_A_CLK_O: R28.2, U5.11 (DIO5)
RADIO_A_CSN: U1.68 (RADIO_A_CSN), U5.19 (NSS)
RADIO_A_IQ_0: R26.2, U5.13 (DIO1)
RADIO_A_IQ_1: R27.2, U5.12 (DIO2)
RADIO_A_IQ_2: R29.2, U5.5 (DIO3)
RADIO_A_IQ_3: R24.2, U5.21 (DIO4)
RADIO_A_RESET: U1.13 (RADIO_CTRL3), U5.15 (NRESET)
RADIO_A_RFIN: C6.2, L12.2, U5.23 (RFI_N)
RADIO_A_RFIP: C5.2, L12.1, U5.22 (RFI_P)
RADIO_B_CLK_32M: R19.2, U7.14 (BUSY)
RADIO_B_CLK_O: R22.2, U7.11 (DIO5)
RADIO_B_CSN: U1.18 (RADIO_B_CSN), U7.19 (NSS)
RADIO_B_IQ0: R20.2, U7.13 (DIO1)
RADIO_B_IQ_1: R21.2, U7.12 (DIO2)
RADIO_B_IQ_2: R23.2, U7.5 (DIO3)
RADIO_B_IQ_3: R18.2, U7.21 (DIO4)
RADIO_B_RESET: U1.28 (RADIO_CTRL9), U7.15 (NRESET)
RADIO_B_RFIN: C10.2, L13.2, U7.23 (RFI_N)
RADIO_B_RFIP: C9.2, L13.1, U7.22 (RFI_P)
RFO: C53.1, L9.1, L10.1, U5.24 (RFO)
RX_ON: R32.1, U1.59 (GPIO4)
SCK: R10.2, R41.2, R49.1, R50.1
SCK_A: U1.65 (RADIO_A_SCK), U5.18 (SCK)
SCK_B: U1.21 (RADIO_B_SCK), U7.18 (SCK)
STM32_MISO: R45.2, U12.12 (PA6)
STM32_MOSI: R48.2, U12.13 (PA7)
STM32_SCK: R50.2, U12.11 (PA5)
SWCLK: TP7.T, U12.24 (PA14)
SWDIO: TP8.T, U12.23 (PA13)
SX1261_BUSY: R67.1, U11.14 (BUSY), U12.9 (PA3)
SX1261_CS: R42.1, R51.1, U11.19 (NSS), U12.14 (PB0)
SX1261_IO1: R61.1, U1.54 (GPIO7), U11.13 (DIO1), U12.15 (PB1)
SX1261_IO2: R63.1, U11.12 (DIO2)
SX1261_IO3: TP9.T, U11.6 (DIO3)
SX1261_RFIN: C68.2, L22.2, U11.22 (RFI_N)
SX1261_RFIP: C73.1, L22.1, U11.21 (RFI_P)
SX1261_RST: R38.1, R60.1, U11.15 (NRESET), U12.18 (PA8)
SX1302_GPIO8: U1.53 (GPIO8), U12.26 (PB3)
TX_ON: R30.1, U1.63 (GPIO2)
TX_RX_SW: R16.2, U1.12 (RADIO_CTRL2)
VCCIO: C3.2, C19.2, C20.2, C25.2, C28.2, C41.2, C42.2, C45.2, C47.2, C76.2, C80.2, C83.2, C86.2, C87.2, C88.2, C89.2, C90.2, Q8.3 (D), R33.1, R34.2, R56.1, R58.1, R65.1, R68.1, R71.1, R80.2, TP1.T, U1.14 (VCC_IO), U1.30 (VCC_IO), U1.47 (VCC_IO), U1.61 (VCC_IO), U12.1 (VDD), U12.5 (VDDA), U12.17 (VDD), U13.3 (VDD)
VCC_1V2: C12.2, C13.2, C23.2, C24.2, C29.2, C40.2, C43.2, C44.2, C71.2, C72.2, L5.2, R79.1, R83.2, TP14.T, U1.5 (VCC_CORE), U1.23 (VCC_CORE), U1.40 (VCC_CORE), U1.56 (VCC_CORE), U6.5 (OUT)
VCC_FEM: C26.2, C27.2, C49.2, C50.2, C51.2, C55.2, FB1.2, L2.2, R2.2, TP6.T, U3.5 (VOUT)
VCC_RADIO: C21.2, C32.2, C33.2, C35.2, C39.2, C48.2, C67.1, L4.2, L7.1, L15.1, R7.2, R36.1, R38.2, R42.2, TP10.T, U4.5 (VOUT), U5.2 (VDD_IN), U5.9 (VBAT_RF), U5.10 (VBAT_DIO), U7.2 (VDD_IN), U7.9 (VBAT_RF), U7.10 (VBAT_DIO), U11.10 (VBAT), U11.11 (VBAT_IO)
VIN: C15.2, C22.2, C30.2, C31.2, C69.2, C70.2, J1.2 (3V3), J1.24 (3V3), J1.39 (3V3), J1.41 (3V3), J1.52 (3V3), Q8.2 (S), R2.1, R7.1, R8.2, R47.1, R78.1, R82.1, TP4.T, U3.1 (VIN), U4.1 (VIN), U6.2 (VIN)

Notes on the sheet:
V1.0
Initial Release
2020/01/02
Vincent
50ohm Impedence
3.3V
300mA
1.2V
500mA
100mA
USB
868
915
SPI
For Power-up delay
V1.1
Add power up delay circuit at VCCIO
Add power up reset circuit for SX1302
Change pins refer to Semtech V3 Schematic
2021/02/18



Board: 4 copper layers, 30.0 x 51.0 mm, 244 parts (68 on the bottom side), 162 nets.

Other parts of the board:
U$45: SEEED-SILK-TNAME-280*268MIL

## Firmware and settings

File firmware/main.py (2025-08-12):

import board
import neopixel
import displayio
import adafruit_displayio_ssd1306
import i2cdisplaybus
from kmk.kmk_keyboard import KMKKeyboard
from kmk.keys import KC
from kmk.scanners import DiodeOrientation
from kmk.modules.macros import Macros
from kmk.modules.encoder import EncoderHandler
from kmk.extensions.rgb import RGB, AnimationModes

from config import Config
from profiles import get_profiles
rgb_max_val = 64
screen_width = 128
screen_height = 32
profiles = get_profiles()
config = Config(num_profiles=len(profiles))

keyboard = KMKKeyboard()
# keyboard.debug_enabled = True  # Enable KMK debug logging
macros = Macros()
encoder_handler = EncoderHandler()
keyboard.modules = [encoder_handler, macros]

initial_color = profiles[config.get_profile_index()].get_color()
rgb = RGB(
    board.D8,
    pixels=(neopixel.NeoPixel(board.D8, 12, pixel_order="GRB"),),
    hue_default=initial_color[0],
    sat_default=initial_color[1],
    val_default=initial_color[2] if initial_color[2] < rgb_max_val else rgb_max_val,
    val_limit=rgb_max_val,
    val_step=1,
    animation_speed=10,
)
keyboard.extensions = [rgb]

displayio.release_displays()
display = adafruit_displayio_ssd1306.SSD1306(
    i2cdisplaybus.I2CDisplayBus(board.I2C(), device_address=0x3C),
    width=screen_width,
    height=screen_height
)
group = displayio.Group()

icon_bitmap = profiles[config.get_profile_index()].get_icon()
icon_palette = displayio.Palette(2)
icon_palette[0] = 0x000000  # Black
icon_palette[1] = 0xFFFFFF  # White

icon_sprite = displayio.TileGrid(
    icon_bitmap,
    pixel_shader=icon_palette,
    x=(screen_width // 2) - 16, 
    y=(screen_height // 2) - 16 
)
group.append(icon_sprite)

display.root_group = group

keyboard.col_pins = (board.D7, board.D3, board.D6)
keyboard.row_pins = (board.D0, board.D10, board.D9)
keyboard.diode_orientation = DiodeOrientation.COL2ROW
encoder_handler.pins = ((board.D2, board.D1, None),)


def enc_click_handler(keyboard):
    configuring = config.toggle_configuring()
    update(configuring=configuring)


def enc_left_handler(keyboard):
    index = config.inc_profile_index(1)
    update(index)


def enc_right_handler(keyboard):
    index = config.inc_profile_index(-1)
    update(index)


def update(profile_index=None, configuring=None):
    if profile_index is None:
        profile_index = config.get_profile_index()
    if configuring is None:
        configuring = config.is_configuring()

    if not (0 <= profile_index < len(profiles)):
        raise ValueError("Profile index out of bounds.")
    print(f"Profile index: {profile_index}")

    if configuring:
        rgb.animation_mode = AnimationModes.BREATHING
    else:
        rgb.animation_mode = AnimationModes.STATIC

    color = profiles[profile_index].get_color()
    rgb.hue = color[0]
    rgb.sat = color[1]
    rgb.val = color[2] if color[2] < rgb.val_limit else rgb.val_limit

    icon_bitmap = profiles[profile_index].get_icon()
    group.pop() 
    icon_palette = displayio.Palette(2)
    icon_palette[0] = 0x000000
    icon_palette[1] = 0xFFFFFF

    icon_sprite = displayio.TileGrid(
        icon_bitmap,
        pixel_shader=icon_palette,
        x=(screen_width // 2) - 16, 
        y=(screen_height // 2) - 16
    )
    group.append(icon_sprite)

    new_keymap = profiles[profile_index].get_keymap()
    new_keymap[0][2] = KC.MACRO(enc_click_handler)

    new_encoder_map = profiles[profile_index].get_encoder_map()
    if config.is_configuring():
        new_encoder_map = (ENC_LEFT, ENC_RIGHT)
    encoder_handler.map = [((new_encoder_map[0], new_encoder_map[1], KC.NO),)]

    keyboard.keymap = new_keymap


ENC_CLICK = KC.MACRO(enc_click_handler)
ENC_LEFT = KC.MACRO(enc_left_handler)
ENC_RIGHT = KC.MACRO(enc_right_handler)

new_keymap = profiles[config.get_profile_index()].get_keymap()
new_keymap[0][2] = KC.MACRO(enc_click_handler)
keyboard.keymap = new_keymap

new_encoder_map = profiles[config.get_profile_index()].get_encoder_map()
encoder_handler.map = [((new_encoder_map[0], new_encoder_map[1], KC.NO),)]

if __name__ == "__main__":
    keyboard.go()

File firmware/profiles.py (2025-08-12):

import displayio
from kmk.keys import KC

def get_profiles(): 
    return [OnShapeProfile(), SlackProfile(), TestProfile()]

class BaseProfile:
    def __init__(self):
        self.bitmap = self._generate_bitmap()

    def _generate_bitmap(self):
        """Generate bitmap from 2D array during initialization."""
        icon_array = self.get_icon_array()
        icon_bitmap = displayio.Bitmap(32, 32, 2)  # 32x32 bitmap with 2 colors (black/white)

        # Validate array dimensions
        if len(icon_array) != 32:
            raise ValueError(f"Icon array must have exactly 32 rows, got {len(icon_array)}")
        
        for i, row in enumerate(icon_array):
            if len(row) != 32:
                raise ValueError(f"Row {i} must have exactly 32 columns, got {len(row)}")
            for j, pixel in enumerate(row):
                if i < 32 and j < 32:  # Safety check
                    icon_bitmap[j, i] = pixel
        return icon_bitmap

    def get_name(self):
        """Return the name of the profile. Keep it as short as possible."""
        raise NotImplementedError("This method should be overridden by subclasses")

    def get_keymap(self):
        """Return a 2D array of the macropad keymap, with top right being KC.NO."""
        raise NotImplementedError("This method should be overridden by subclasses")

    def get_encoder_map(self):
        """Return a tuple of 2 values, one for left and right encoder turns."""
        raise NotImplementedError("This method should be overridden by subclasses")

    def get_color(self):
        """Return a tuple of HSV values (0-255) for the profile color."""
        raise NotImplementedError("This method should be overridden by subclasses")

    def get_icon_array(self):
        """Return a 32x32 2D array of 0s and 1s for the profile icon."""
        raise NotImplementedError("This method should be overridden by subclasses")

    def get_icon(self):
        """Return the generated bitmap for the profile icon."""
        return self.bitmap


class OnShapeProfile(BaseProfile):
    def get_name(self):
        return "OnShape"

    def get_keymap(self):
        return [[
            KC.LSFT(KC.X),  KC.LSFT(KC.N2), KC.NO,          # Section view, Rear view
            KC.LSFT(KC.N3), KC.LSFT(KC.N7), KC.LSFT(KC.N4), # Left view, Iso view, Right view
            KC.LSFT(KC.N5), KC.LSFT(KC.N1), KC.LSFT(KC.N6), # Top view, Front view, Bottom view
        ]]

    def get_encoder_map(self):
        return (KC.Z, KC.LSFT(KC.Z)) # Zoom out, Zoom in

    def get_color(self):
        return (85, 255, 255)

    def get_icon_array(self):
        return [
            [0,0,0,0,0,0,0,0,0,0,0,0,0,0,0,1,0,0,0,0,0,0,0,0,0,0,0,0,0,0,0,0],
            [0,0,0,0,0,0,0,0,0,0,0,0,0,1,1,1,1,1,0,0,0,0,0,0,0,0,0,0,0,0,0,0],
            [0,0,0,0,0,0,0,0,0,0,0,1,1,1,1,1,1,1,1,1,0,0,0,0,0,0,0,0,0,0,0,0],
            [0,0,0,0,0,0,0,0,0,0,1,1,1,1,1,1,1,1,1,1,0,0,0,0,0,0,0,0,0,0,0,0],
            [0,0,0,0,0,0,0,0,1,1,1,1,1,1,1,1,1,1,0,0,0,0,0,0,0,0,0,0,0,0,0,0],
            [0,0,0,0,0,0,1,1,1,1,1,1,1,1,1,1,1,0,0,0,0,1,1,1,1,0,0,0,0,0,0,0],
            [0,0,0,0,0,1,1,1,1,1,1,1,1,1,1,0,0,0,0,1,1,1,1,1,1,1,1,0,0,0,0,0],
            [0,0,0,1,1,1,1,1,1,1,1,1,1,0,0,0,0,0,1,1,1,1,1,1,1,1,1,1,0,0,0,0],
            [0,0,1,1,1,1,1,1,1,1,1,1,0,0,0,0,0,0,0,1,1,1,1,1,1,1,1,1,1,0,0,0],
            [0,0,1,1,1,1,1,1,1,1,0,0,0,0,1,1,1,0,0,0,0,1,1,1,1,1,1,1,1,0,0,0],
            [0,0,1,1,1,1,1,1,0,0,0,0,1,1,1,1,1,0,0,0,0,0,0,1,1,1,1,1,1,0,0,0],
            [0,0,1,1,1,1,1,0,0,0,0,1,1,1,1,0,0,0,1,1,1,0,0,0,1,1,1,1,1,0,0,0],
            [0,0,1,1,1,1,1,0,0,1,1,1,1,1,0,0,0,1,1,1,1,1,0,0,1,1,1,1,1,0,0,0],
            [0,0,1,1,1,1,1,0,0,1,1,1,0,0,0,0,0,0,0,1,1,1,0,0,1,1,1,1,1,0,0,0],
            [0,0,1,1,1,1,1,0,0,1,1,1,0,0,0,0,0,0,0,1,1,1,0,0,1,1,1,1,1,0,0,0],
            [0,0,1,1,1,1,1,0,0,1,1,1,0,0,0,0,0,0,0,1,1,1,0,0,1,1,1,1,1,0,0,0],
            [0,0,0,0,1,1,1,0,0,0,0,1,0,0,0,0,0,0,0,1,1,1,0,0,1,1,1,1,1,0,0,0],
            [0,0,0,0,0,0,1,0,0,1,0,0,0,0,0,0,0,0,0,1,1,1,0,0,1,1,1,1,1,0,0,0],
            [0,0,1,0,0,0,0,0,0,1,1,1,0,0,0,0,0,0,0,1,1,1,0,0,1,1,1,1,1,0,0,0],
            [0,0,1,1,1,0,0,0,0,1,1,1,1,1,0,0,0,1,0,1,1,1,0,0,1,1,1,1,1,0,0,0],
            [0,0,1,1,1,1,1,0,0,0,0,1,1,1,1,0,1,1,0,1,0,0,0,0,1,1,1,1,1,0,0,0],
            [0,0,1,1,1,1,1,1,0,0,0,0,0,1,1,1,1,1,0,0,0,0,0,0,1,1,1,1,1,0,0,0],
            [0,0,1,1,1,1,1,1,1,1,0,0,0,0,1,1,1,0,0,0,0,1,0,0,1,1,1,1,1,0,0,0],
            [0,0,1,1,1,1,1,1,1,1,1,1,0,0,0,0,0,0,0,1,1,1,0,0,1,1,1,1,1,0,0,0],
            [0,0,0,1,1,1,1,1,1,1,1,1,1,1,0,0,0,1,1,1,1,1,0,0,1,1,1,1,0,0,0,0],
            [0,0,0,0,0,1,1,1,1,1,1,1,1,1,1,0,1,1,1,1,1,1,0,0,1,1,0,0,0,0,0,0],
            [0,0,0,0,0,0,0,1,1,1,1,1,1,1,1,1,1,1,1,1,1,1,0,0,0,0,0,0,0,0,0,0],
            [0,0,0,0,0,0,0,0,0,1,1,1,1,1,1,1,1,1,1,1,1,1,0,0,0,0,0,0,0,0,0,0],
            [0,0,0,0,0,0,0,0,0,0,1,1,1,1,1,1,1,1,1,1,1,0,0,0,0,0,0,0,0,0,0,0],
            [0,0,0,0,0,0,0,0,0,0,0,0,1,1,1,1,1,1,1,0,0,0,0,0,0,0,0,0,0,0,0,0],
            [0,0,0,0,0,0,0,0,0,0,0,0,0,0,1,1,1,0,0,0,0,0,0,0,0,0,0,0,0,0,0,0],
            [0,0,0,0,0,0,0,0,0,0,0,0,0,0,0,0,0,0,0,0,0,0,0,0,0,0,0,0,0,0,0,0]
        ]
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

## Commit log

2025-06-07 Upload PCB
    [1x7 Male Pin Header.step, Cherry MX-No LED.step, EC11_Rotary_Encoder_Switched.step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]
2025-06-07 Add production files
    [case_mid.stl, case_top.stl]
2025-06-14 Fix OLED voltage
    [hackpad.kicad_pcb, hackpad.kicad_sch]
2025-07-27 Update hackpad
    [hackpad.kicad_pcb, hackpad.kicad_sch]
2025-07-27 Upate Hackpad
    [hackpad-B_Cu.gbl, hackpad-B_Cu.gbr, hackpad-B_Mask.gbr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]
